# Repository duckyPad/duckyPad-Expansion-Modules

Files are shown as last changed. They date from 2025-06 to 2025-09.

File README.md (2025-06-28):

# duckyPad Expansion Module

[Get duckyPad Pro](https://www.tindie.com/products/37399/) | [Official Discord](https://discord.gg/4sJCBx5) | [Project Page](https://github.com/dekuNukem/duckyPad-Pro) | [Table of Contents](#table-of-contents)

--------------

duckyPad Expansion Module lets you wire up external **switches / buttons / foot pedals** to your duckyPad Pro.

* **8 Channels** Per Module

* **Daisy-Chain** up to 32 Channels

* USB-C Connector





## Table of Contents

- [Kit Assembly](#kit-assembly)
- [Connection Overview](#connection-overview)
	- [Terminal Block](#connection-terminal-block)
	- [3.5mm Audio Jack](#connection-35mm-audio-jack)
	- [Pin Headers](#connection-pin-headers)
- [Key Test](#key-test)
- [Configurator](#configurator)

## Kit Assembly

* **Wash your hands first** to discharge static electricity

You should have the following parts:



Insert the `8mm Screws` in `Bottom Plate`:



Place **something rigid** against the back, and flip over.

The screws should stay in place.

Put on **2.5mm Nylon Spacers**.



Insert the `Circuit Board`.

Then the `8mm Metal Spacer`

* **Moderately tighten** with a socket bit if available

* Avoid scratching the PCB or nearby components.



Leave the `Top Plate` off for now.

You can install it after everything is wired up.

## Back to duckyPad!

If you're just starting, **set up your duckyPad first by [following the User Guide](https://dekunukem.github.io/duckyPad-Pro/doc/getting_started.html)**

Play with scripts on built-in switches and encoders, continue here once familiarised.

## Connection Overview

**8 Channels** are available per module.

* Numbered 1 to 8
* A channel is **considered active** when it is **shorted to ground (GND)**.

Therefore, to wire up a switch, you just need to:

* Connect **one side** to **GND**
* And the **other side** to the **desired channel**

---------

You can make connections via:

* Terminal Block
* 3.5mm Jack
* Pin Headers

## Connection: Terminal Block

Take a look at the `terminal block`:



Contains **Channel 1 to 7** and **GND**

To wire up a switch, connect it between a channel and GND.

-------

As an example, here's a simple button with two wires:



* When not pushed, the wires are isolated.
* When pushed, they are **connected together**.

Therefore, we just need to attach one wire to GND, and the other to a channel.

* Flip up the lever for GND and the desired channel



* Strip around half inch / 1.2cm of conductor
* Insert into the hole
* Flip lever back down



## Connection: 3.5mm Audio Jack

Two 3.5mm TRS (Tip, Ring, Sleeve) connectors are available.

Sleeve is connected to GND.

Tip and Ring are connected to channels shown below.



## Connection: Pin Headers

All channels are also available on pin headers.

You can install a header or solder wires directly to them.



## Key Test

Use a USB-C cable and connect the module as shown.

* Make sure the `Towards duckyPad` marking faces duckyPad

* The other end is used for daisy-chaining



Press the `Key Test` script in `Welcome` profile



Press a built-in switch, the screen should respond.

Then activate a channel on the expansion module.

The corresponding LED should light up:



The screen should show too:



If so, congrats! Your wiring is correct.

## Configurator

You can assign actions to expansion channels just like any other key.

Module 1 is closest to duckyPad, up to 4 can be daisy-chained.



Some notes:

* If using a flip switch, select `Disable Auto-Repeat`.
* So the script doesn't repeat after changing state.



* Each channel can have different scripts for `onPress` and `onRelease`.
	* `onPress` is when a channel goes from inactive to active
	* `onRelase` is the opposite



## Communication Protocol

[See this page](tech_notes.md)

## Questions or Comments?

Please feel free to [open an issue](https://github.com/dekuNukem/duckypad-pro/issues), ask in the [official duckyPad discord](https://discord.gg/4sJCBx5), or email `dekuNukem`@`gmail`.`com`!

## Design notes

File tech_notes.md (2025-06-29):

# duckyPad Expansion Module (DPEM) Communication Protocols

[Get duckyPad Pro](https://www.tindie.com/products/37399/) | [Official Discord](https://discord.gg/4sJCBx5) | [Project Page](https://github.com/dekuNukem/duckyPad-Pro)

-----------

## Hardware Description

Each DPEM has **two USB-C ports** for daisy-chaining:

* One for **Towards-duckyPad (TD)** communication.

* The other for **Away-from-duckyPad (AFD)** communication.

DPEM talks to each other using standard **TTL serial**:

* 115200 8N1

* The D+ and D- lines carry TX and RX signals

Microcontroller is STM32F042F6P6:

* Monitors 8 input channels

* Negotiates with neighbouring devices

* UART1 for TD, UART2 for AFD.

## Global Channel ID (GCID)

A DPEM has 8 channels, each of which has a unique GCID.

The GCID of a DPEM's **first channel** is its **Start ID**.

* The DPEM closest to duckyPad has a Start ID of 0, with GCID from 0 to 7.
* The next DPEM has Start ID of 8, with GCID from 8 to 15.
* And so on, up to 32 channels total.

## Packet Format

DPEM uses simple **1-byte** data packets to communicate.

* Top 2 bits: **Command Type**.

* Lower 6 bits: **Payload**.

```
 7 6 5 4 3 2 1 0
+---------------+
|CMD|  PAYLOAD  |
+---------------+
```

| CMD | Description | Direction |Payload|
| --- | --- | --- | --- |
| 00  | `Ask Start ID` | TD | Firmware Version|
| 01  | `Assign Start ID` | AFD | Start ID|
| 10  | `SW Pressed` | TD | GCID|
| 11  | `SW Released` | TD | GCID|

## ID Assignment

DPEM powers up in **uninitialized** state.

* It periodically sends `Ask Start ID` to TD.

* TD replies with `Assign Start ID`.

* Now this DPEM has a start ID and is **initialized**.

## Event Handling

Once initialized, DPEM monitors the **channel status** and **AFD activity**.

* When **one of its own channels** changes state, it sends `SW Pressed` / `SW Released` to TD.

* When `SW Pressed` / `SW Released` is received from AFD, it is passed as-is to TD.

* When `Ask Start ID` is received from AFD, it replies with `Assign Start ID`, which is its `last_channel_ID + 1`.

## Questions or Comments?

Please feel free to [open an issue](https://github.com/dekuNukem/duckypad-pro/issues), ask in the [official duckyPad discord](https://discord.gg/4sJCBx5), or email `dekuNukem`@`gmail`.`com`!

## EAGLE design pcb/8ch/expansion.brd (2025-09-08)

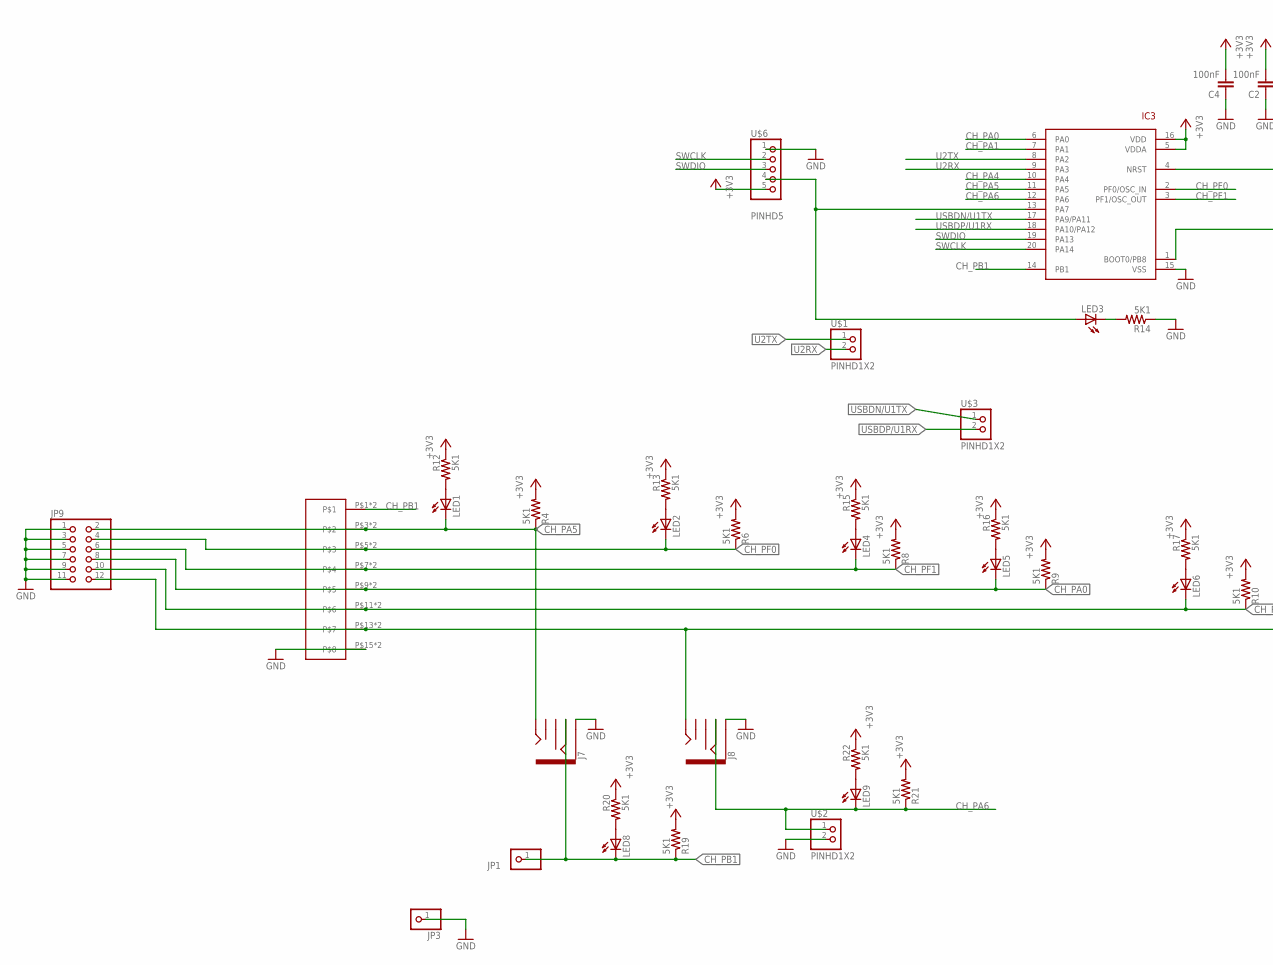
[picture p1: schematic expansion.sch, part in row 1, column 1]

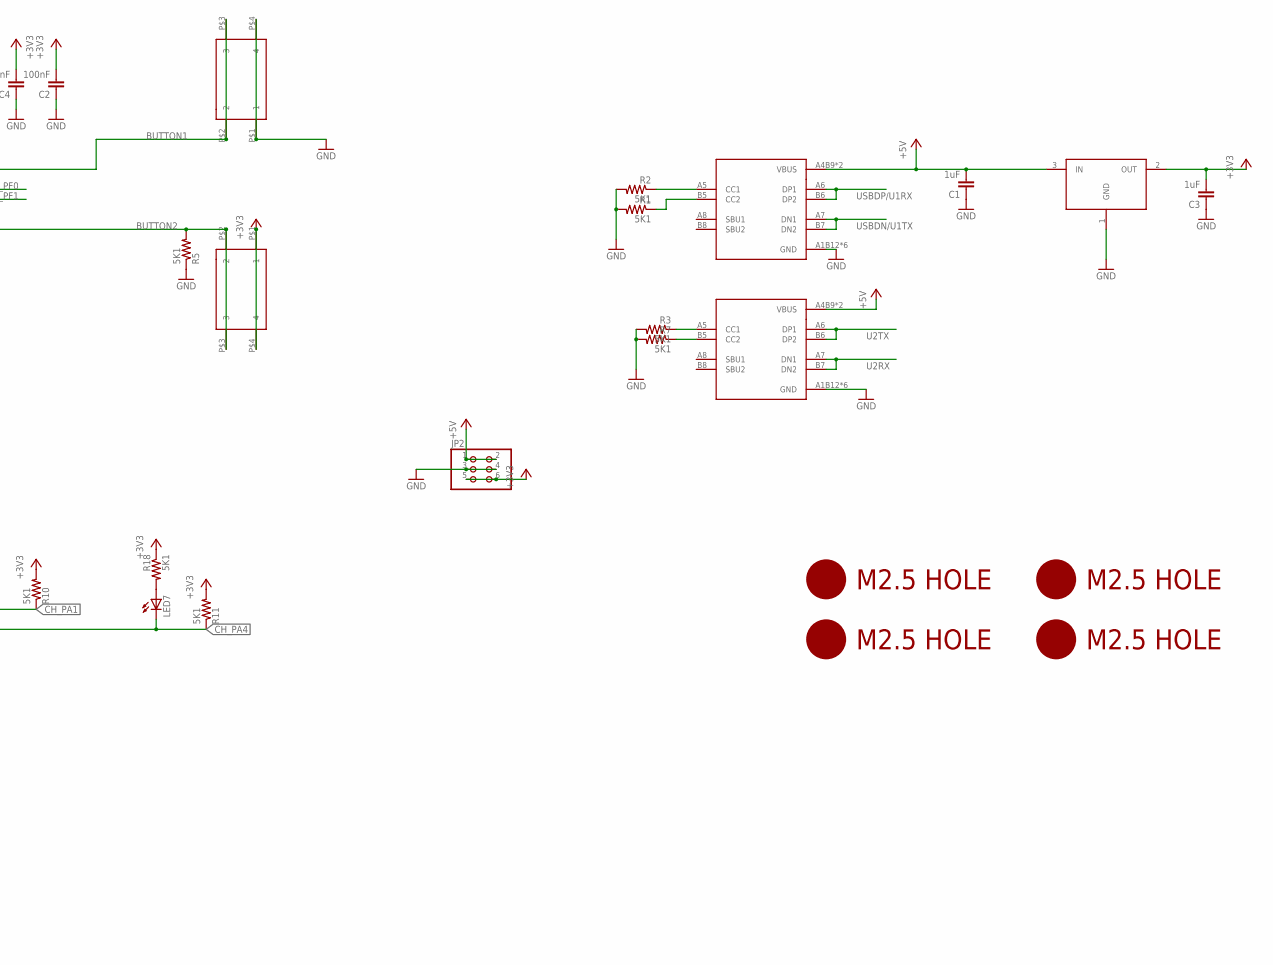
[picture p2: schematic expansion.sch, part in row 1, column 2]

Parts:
C1, C3: 1uF; 0805
C2, C4: 100nF; 0805
IC3: STM32F042F4; TSSOP20
J7, J8: AUDIO_JACK_3.5MM_PTH; AUDIO-JACK
JP1, JP3: PINHD-1X1; 1X01
JP2: PINHD-2X3; 2X03
JP9: PINHD-2X6; 2X06
LED1, LED2, LED3, LED4, LED5, LED6, LED7, LED8, LED9: LEDCHIP-LED0805; CHIP-LED0805
R1, R2, R3, R4, R5, R6, R7, R8, R9, R10, R11, R12, R13, R14, R15, R16, R17, R18, R19, R20, R21, R22: 5K1; 0805
SW3, SW4: 324_SW; 342_SWICH_FOOT
U1, U2: USBC_16P; USBC_16P_FOOT
U4: XC6206_DEV; SOT23R_INFINEON
U$1, U$2, U$3: PINHD1X2; 1X02
U$6: PINHD5; 1X05
U$8, U$9, U$10, U$11: M2.5HOLE
U$14: DG2204R-5.0-8DG2204-8; DG2204R-8-THERMAL

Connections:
+3V3: C2.2, C3.2, C4.2, IC3.5 (VDDA), IC3.16 (VDD), JP2.5, JP2.6, R4.2, R6.2, R8.2, R9.2, R10.2, R11.2, R12.1, R13.1, R15.1, R16.1, R17.1, R18.1, R19.2, R20.1, R21.2, R22.1, SW4.P$1 (1), SW4.P$4 (4), U4.2 (OUT), U$6.5
+5V: C1.2, JP2.1, JP2.2, U1.A4B9 (VBUS), U1.B4A9 (VBUS), U2.A4B9 (VBUS), U2.B4A9 (VBUS), U4.3 (IN)
BUTTON1: IC3.4 (NRST), SW3.P$2 (2), SW3.P$3 (3)
BUTTON2: IC3.1 (BOOT0/PB8), R5.2, SW4.P$2 (2), SW4.P$3 (3)
CH_PA0: IC3.6 (PA0), JP9.8, LED5.C, R9.1, U$14.P$9, U$14.P$10
CH_PA1: IC3.7 (PA1), JP9.10, LED6.C, R10.1, U$14.P$11, U$14.P$12
CH_PA4: IC3.10 (PA4), J8.TIP, JP9.12, LED7.C, R11.1, U$14.P$13, U$14.P$14
CH_PA5: IC3.11 (PA5), J7.TIP, JP9.2, LED1.C, R4.1, U$14.P$3, U$14.P$4
CH_PA6: IC3.12 (PA6), J8.RING, LED9.C, R21.1, U$2.1
CH_PB1: IC3.14 (PB1), J7.RING, JP1.1, LED8.C, R19.1, U$14.P$1, U$14.P$2
CH_PF0: IC3.2 (PF0/OSC_IN), JP9.4, LED2.C, R6.1, U$14.P$5, U$14.P$6
CH_PF1: IC3.3 (PF1/OSC_OUT), JP9.6, LED4.C, R8.1, U$14.P$7, U$14.P$8
GND: C1.1, C2.1, C3.1, C4.1, IC3.15 (VSS), J7.SLEEVE, J8.SLEEVE, JP2.3, JP2.4, JP3.1, JP9.1, JP9.3, JP9.5, JP9.7, JP9.9, JP9.11, R1.2, R2.2, R3.2, R5.1, R7.2, R14.1, SW3.P$1 (1), SW3.P$4 (4), U1.A1B12 (GND), U1.B11A12 (GND), U1.P$13 (GND), U1.P$14 (GND), U1.P$15 (GND), U1.P$16 (GND), U2.A1B12 (GND), U2.B11A12 (GND), U2.P$13 (GND), U2.P$14 (GND), U2.P$15 (GND), U2.P$16 (GND), U4.1 (GND), U$2.2, U$6.1, U$14.P$15, U$14.P$16
unnamed: R3.1, U1.A5 (CC1)
unnamed: R7.1, U1.B5 (CC2)
unnamed: LED1.A, R12.2
unnamed: LED2.A, R13.2
unnamed: LED4.A, R15.2
unnamed: LED5.A, R16.2
unnamed: LED6.A, R17.2
unnamed: LED7.A, R18.2
unnamed: LED8.A, R20.2
unnamed: IC3.13 (PA7), LED3.A, U$6.4
unnamed: LED3.C, R14.2
unnamed: LED9.A, R22.2
unnamed: R1.1, U2.B5 (CC2)
unnamed: R2.1, U2.A5 (CC1)
SWCLK: IC3.20 (PA14), U$6.2
SWDIO: IC3.19 (PA13), U$6.3
U2RX: IC3.9 (PA3), U1.A7 (DN1), U1.B7 (DN2), U$1.2
U2TX: IC3.8 (PA2), U1.A6 (DP1), U1.B6 (DP2), U$1.1
USBDN/U1TX: IC3.17 (PA9/PA11), U2.A7 (DN1), U2.B7 (DN2), U$3.1
USBDP/U1RX: IC3.18 (PA10/PA12), U2.A6 (DP1), U2.B6 (DP2), U$3.2

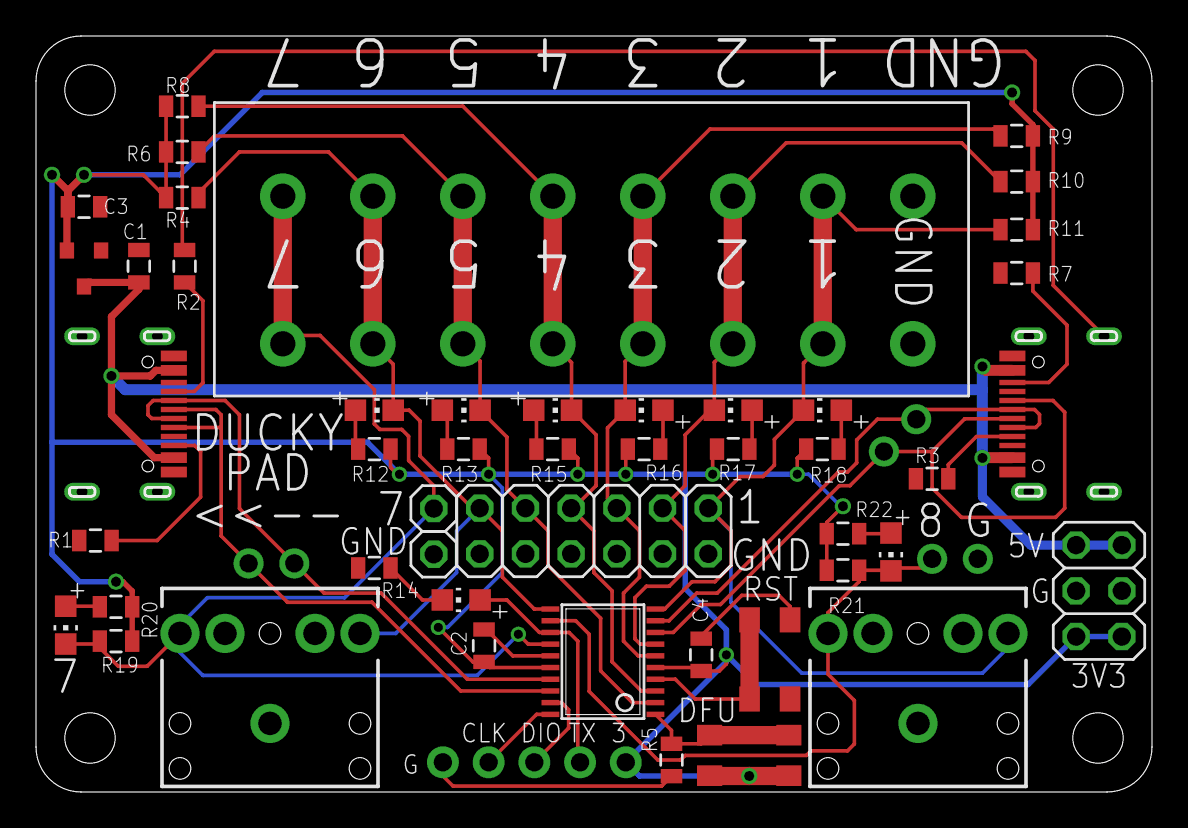
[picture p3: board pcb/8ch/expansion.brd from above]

Board: 2 copper layers, 62.0 x 42.0 mm, 56 parts (0 on the bottom side), 33 nets.

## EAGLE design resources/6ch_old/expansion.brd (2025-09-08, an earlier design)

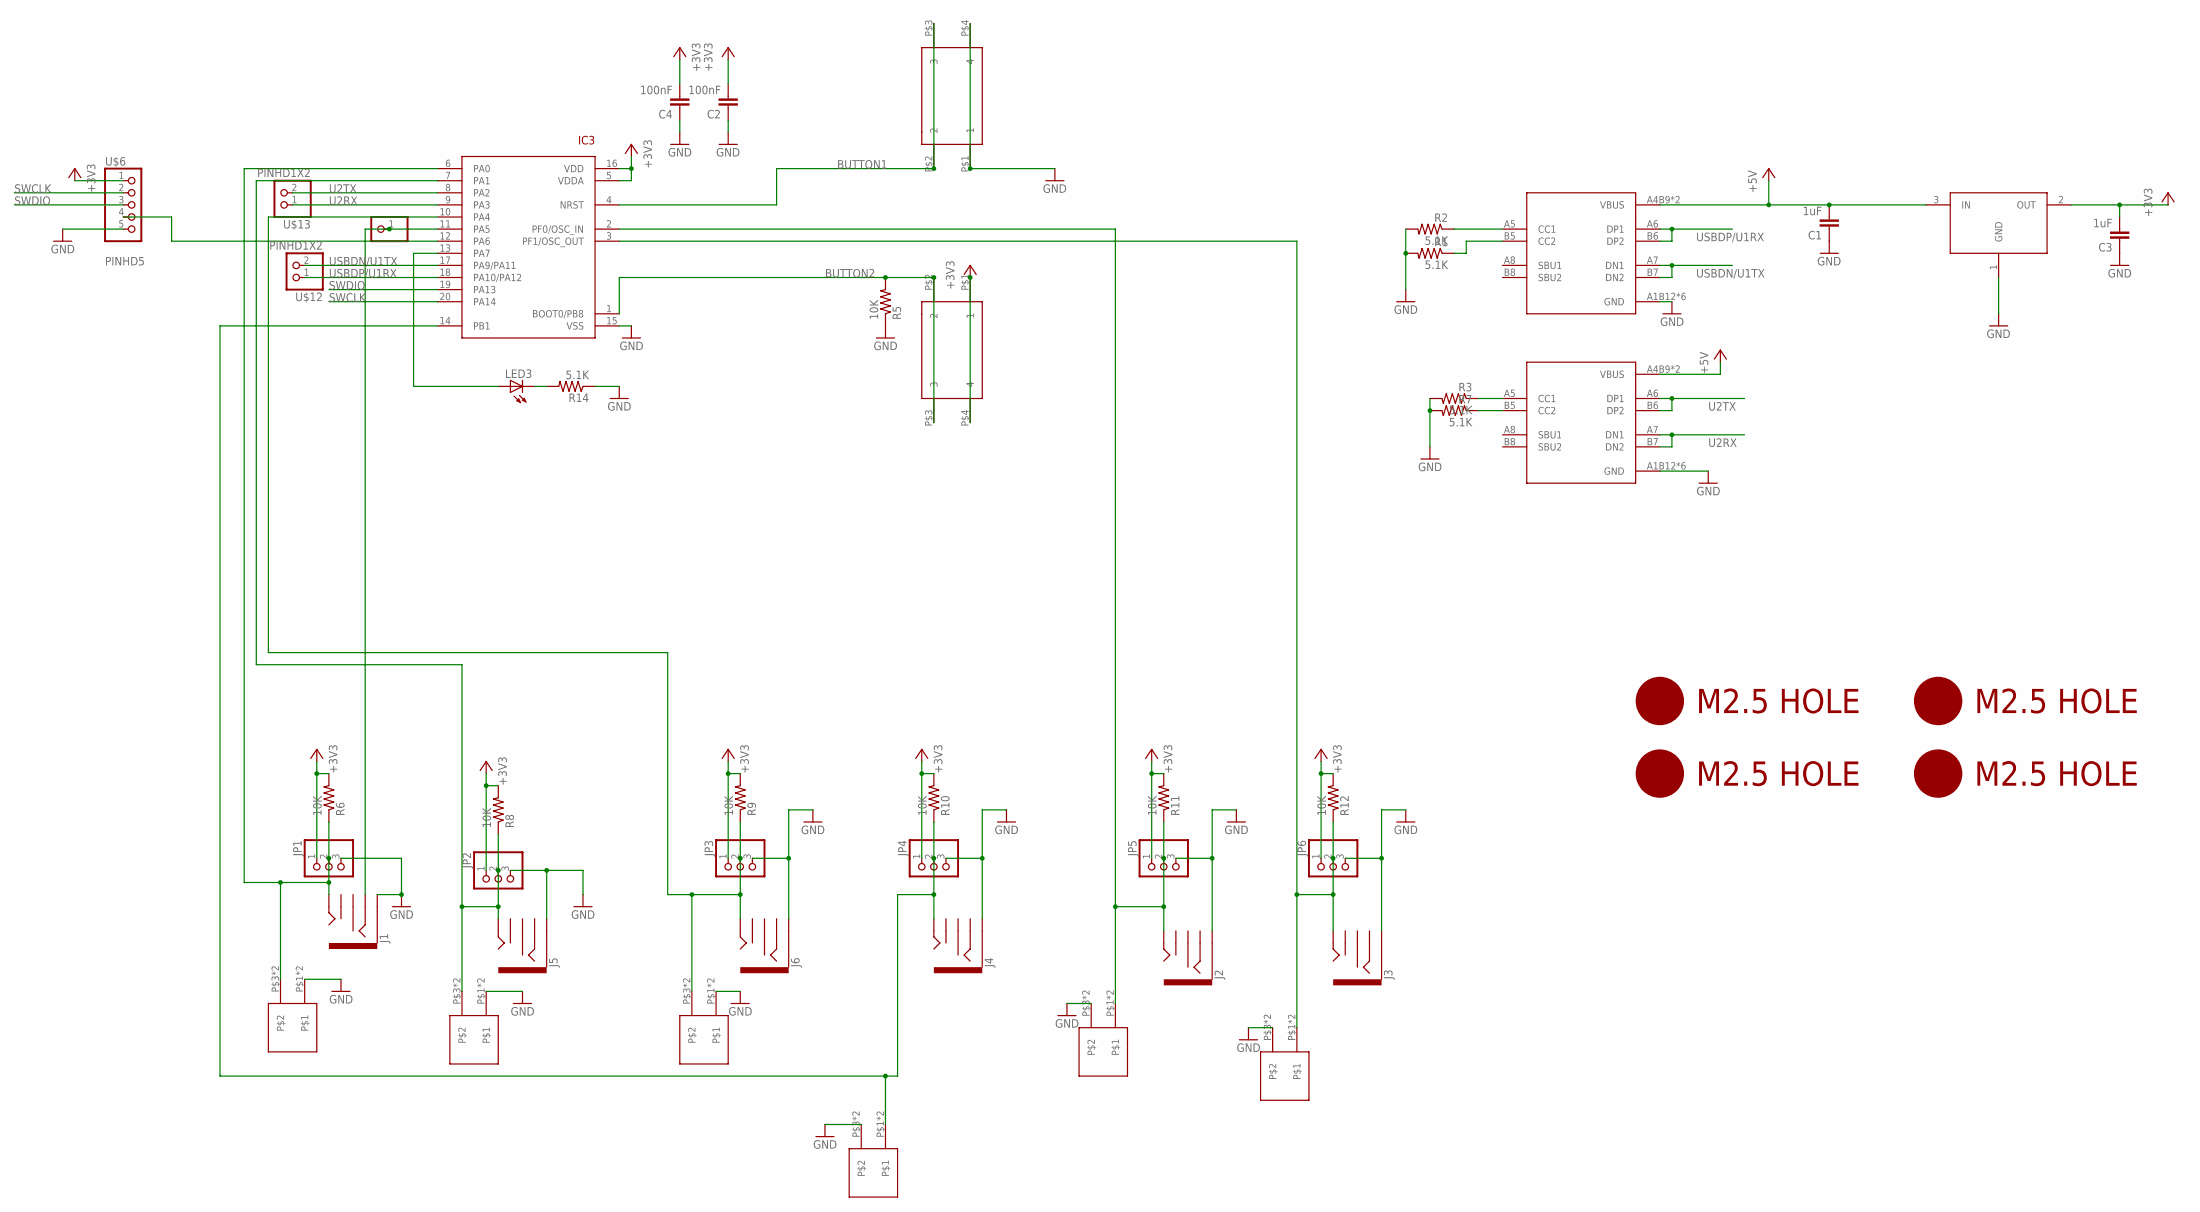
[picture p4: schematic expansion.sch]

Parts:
C1, C3: 1uF; 0805
C2, C4: 100nF; 0805
IC3: STM32F042F4; TSSOP20
J1, J2, J3, J4, J5, J6: AUDIO_JACK_3.5MM_PTH; AUDIO-JACK
JP1, JP2, JP3, JP4, JP5, JP6: PINHD-1X3; 1X03
JP7: PINHD-1X1CB; 1X01-CLEANBIG
LED3: LEDCHIP-LED0805; CHIP-LED0805
R1, R2, R3, R7, R14: 5.1K; 0805
R5, R6, R8, R9, R10, R11, R12: 10K; 0805
SW3, SW4: 324_SW; 342_SWICH_FOOT
U1, U2: USBC_16P; USBC_16P_FOOT
U4: XC6206_DEV; SOT23R_INFINEON
U$1, U$2, U$3, U$4, U$5, U$7: DG2204R-2
U$6: PINHD5; 1X05
U$8, U$9, U$10, U$11: M2.5HOLE
U$12, U$13: PINHD1X2; 1X02

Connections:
+3V3: C2.2, C3.2, C4.2, IC3.5 (VDDA), IC3.16 (VDD), JP1.1, JP2.1, JP3.1, JP4.1, JP5.1, JP6.1, R6.2, R8.2, R9.2, R10.2, R11.2, R12.2, SW4.P$1 (1), SW4.P$4 (4), U4.2 (OUT), U$6.1
+5V: C1.2, U1.A4B9 (VBUS), U1.B4A9 (VBUS), U2.A4B9 (VBUS), U2.B4A9 (VBUS), U4.3 (IN)
BUTTON1: IC3.4 (NRST), SW3.P$2 (2), SW3.P$3 (3)
BUTTON2: IC3.1 (BOOT0/PB8), R5.2, SW4.P$2 (2), SW4.P$3 (3)
CH1: IC3.6 (PA0), J1.TIP, JP1.2, R6.1, U$4.P$3, U$4.P$4
CH2: IC3.7 (PA1), J5.TIP, JP2.2, R8.1, U$5.P$3, U$5.P$4
CH3: IC3.10 (PA4), J6.TIP, JP3.2, R9.1, U$7.P$3, U$7.P$4
CH4: IC3.14 (PB1), J4.TIP, JP4.2, R10.1, U$1.P$1, U$1.P$2
CH5: IC3.2 (PF0/OSC_IN), J2.TIP, JP5.2, R11.1, U$2.P$1, U$2.P$2
CH6: IC3.3 (PF1/OSC_OUT), J3.TIP, JP6.2, R12.1, U$3.P$1, U$3.P$2
GND: C1.1, C2.1, C3.1, C4.1, IC3.15 (VSS), J1.SLEEVE, J2.SLEEVE, J3.SLEEVE, J4.SLEEVE, J5.SLEEVE, J6.SLEEVE, JP1.3, JP2.3, JP3.3, JP4.3, JP5.3, JP6.3, R1.2, R2.2, R3.2, R5.1, R7.2, R14.1, SW3.P$1 (1), SW3.P$4 (4), U1.A1B12 (GND), U1.B11A12 (GND), U1.P$13 (GND), U1.P$14 (GND), U1.P$15 (GND), U1.P$16 (GND), U2.A1B12 (GND), U2.B11A12 (GND), U2.P$13 (GND), U2.P$14 (GND), U2.P$15 (GND), U2.P$16 (GND), U4.1 (GND), U$1.P$3, U$1.P$4, U$2.P$3, U$2.P$4, U$3.P$3, U$3.P$4, U$4.P$1, U$4.P$2, U$5.P$1, U$5.P$2, U$6.5, U$7.P$1, U$7.P$2
unnamed: R3.1, U1.A5 (CC1)
unnamed: R7.1, U1.B5 (CC2)
unnamed: LED3.C, R14.2
unnamed: IC3.13 (PA7), LED3.A
unnamed: IC3.11 (PA5), J1.RING, JP7.1
unnamed: IC3.12 (PA6), U$6.4
unnamed: R1.1, U2.B5 (CC2)
unnamed: R2.1, U2.A5 (CC1)
SWCLK: IC3.20 (PA14), U$6.2
SWDIO: IC3.19 (PA13), U$6.3
U2RX: IC3.9 (PA3), U1.A7 (DN1), U1.B7 (DN2), U$13.1
U2TX: IC3.8 (PA2), U1.A6 (DP1), U1.B6 (DP2), U$13.2
USBDN/U1TX: IC3.17 (PA9/PA11), U2.A7 (DN1), U2.B7 (DN2), U$12.2
USBDP/U1RX: IC3.18 (PA10/PA12), U2.A6 (DP1), U2.B6 (DP2), U$12.1

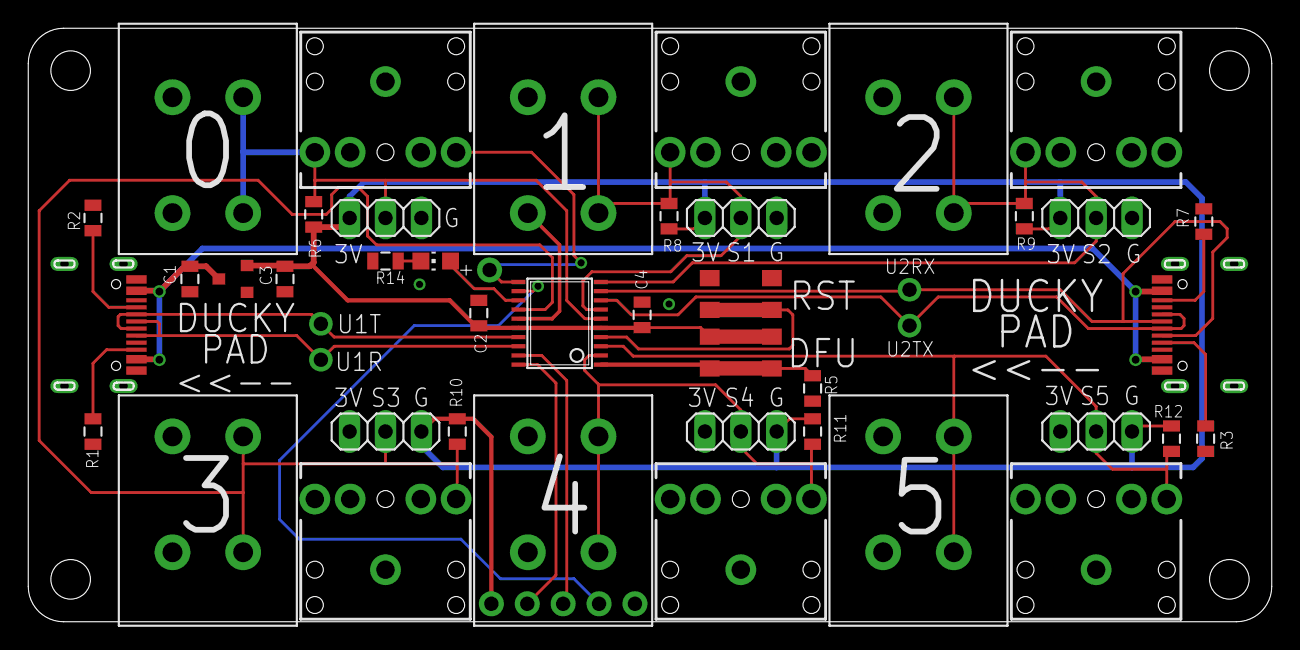
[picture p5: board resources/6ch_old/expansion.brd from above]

Board: 2 copper layers, 88.0 x 42.0 mm, 49 parts (0 on the bottom side), 25 nets.

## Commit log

2025-09-08 lined up usb port
    [expansion.brd, expansion.sch]
2025-09-08 added thermal on terminal block, adjusted terminal block and TRS connector location
    [expansion.brd, expansion.sch]
2025-09-08 adjusted silkscreen
    [expansion.brd]

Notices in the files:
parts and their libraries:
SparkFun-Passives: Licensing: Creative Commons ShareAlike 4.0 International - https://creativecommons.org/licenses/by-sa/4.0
